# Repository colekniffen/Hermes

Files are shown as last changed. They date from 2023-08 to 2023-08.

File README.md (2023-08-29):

# Hermes
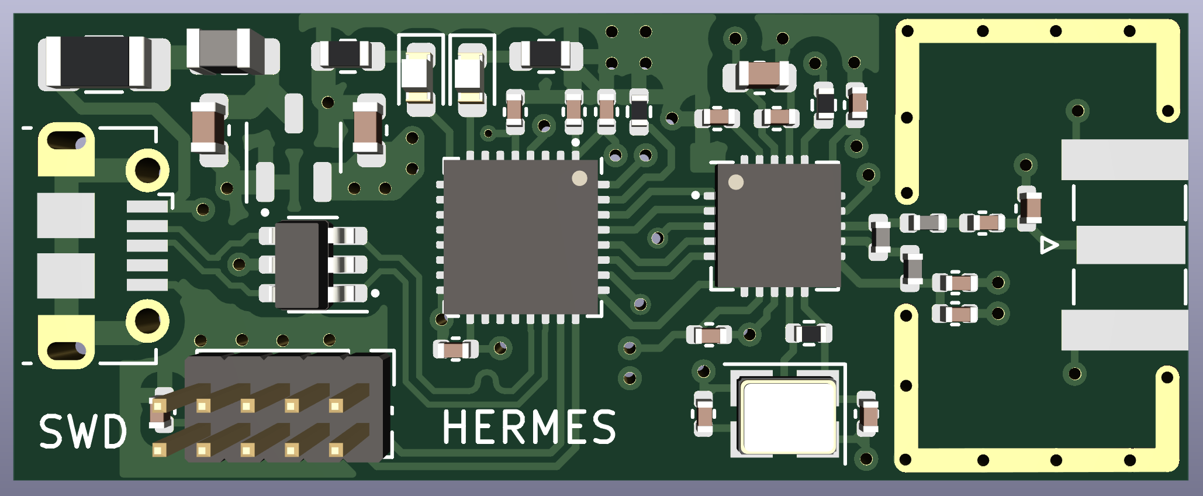
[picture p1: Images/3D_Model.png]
3D Model

A small form factor, low power, RF module with a programmable STM32.  The goal of this project was to make a small board to mess around with RF and some basic DSP.

## Stack-up
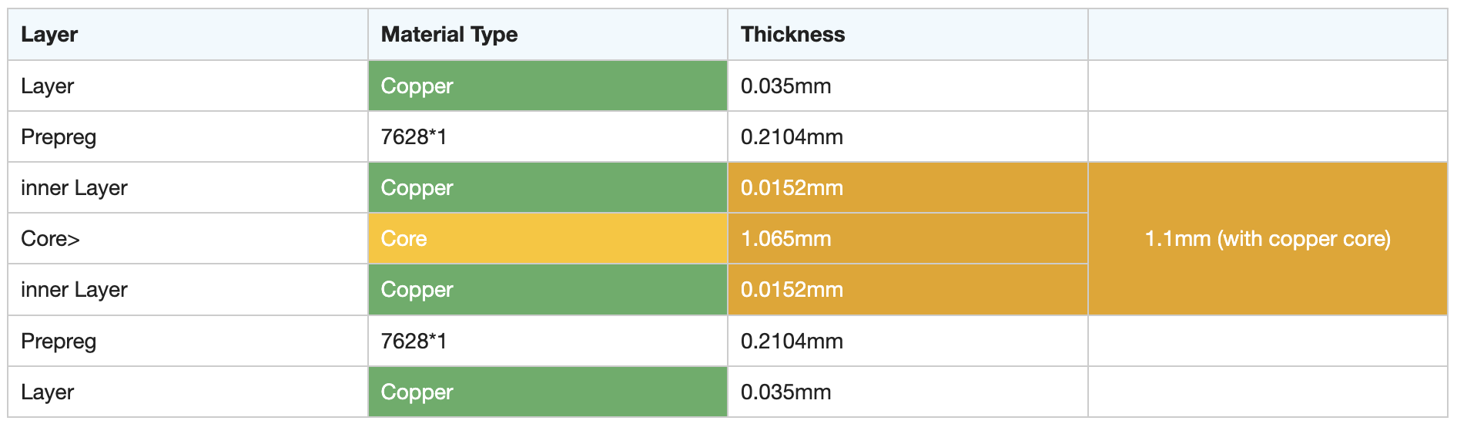
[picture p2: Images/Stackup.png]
PCB Stack-up

I planned to manufacture this board through JLC PCB.  The service allows for cost-effective manufacturing with reasonable accuracy and constraints.  I decided to use an impedance-controlled, 4-layer stack-up because of the RF section (JLC04161H-7628).  This board is 1.6 mm thick with an outer copper weight of 1oz and inner copper weight of 0.5oz.  The stack-up information is important in determining the USB differential and RF antenna trace widths and/or spacing. 

## Design Considerations
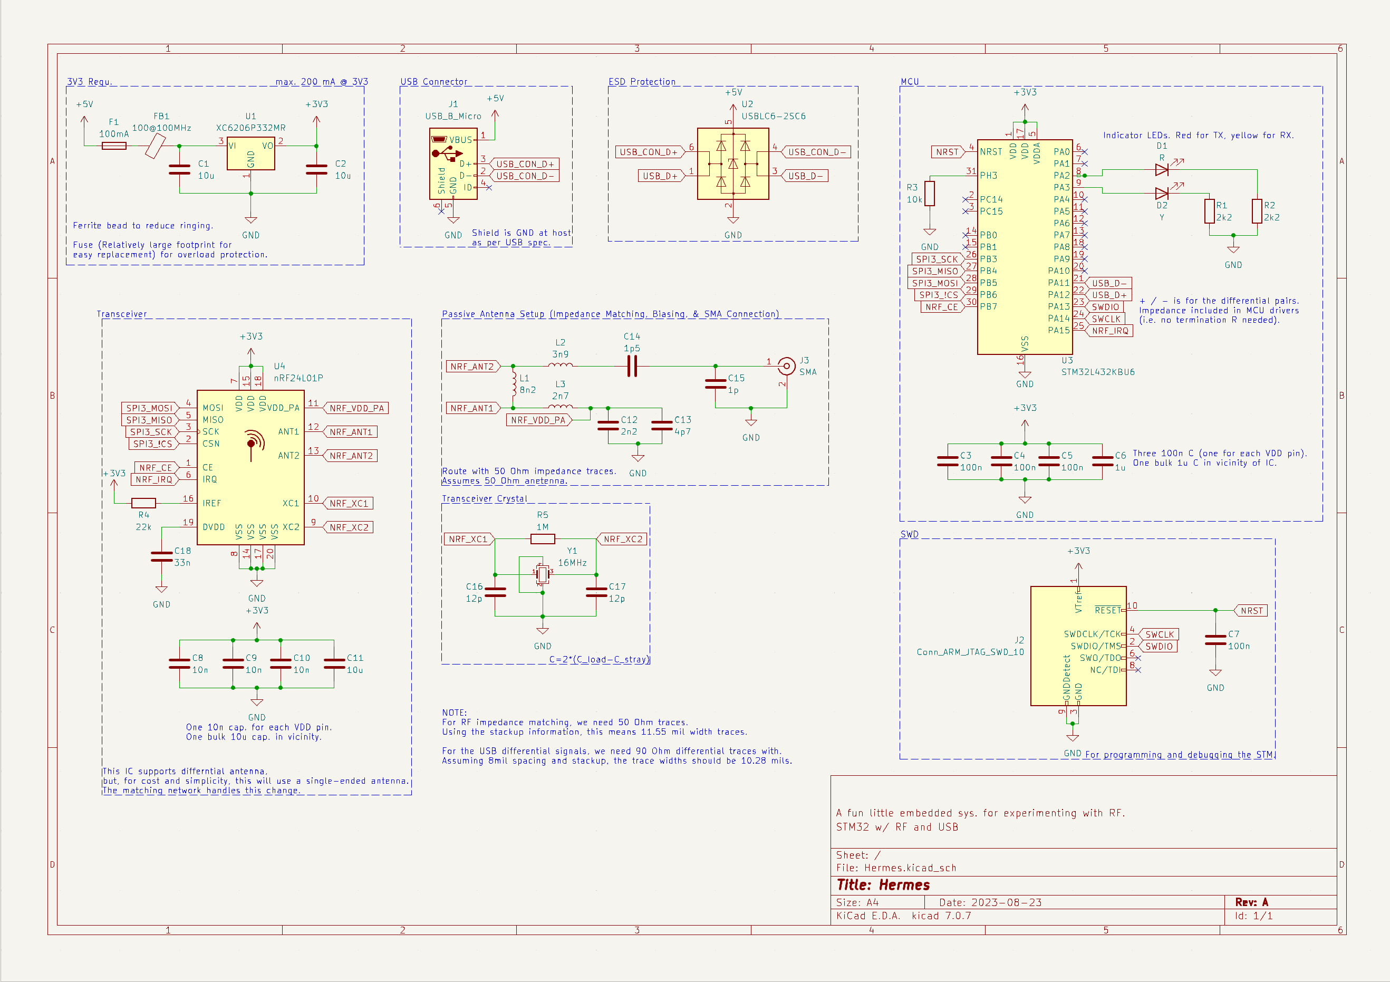
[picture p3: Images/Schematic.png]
Schematic
 
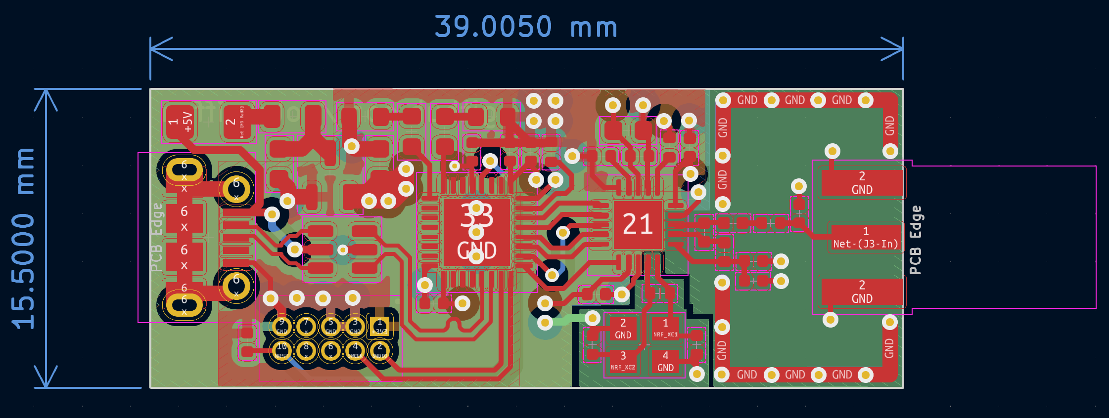
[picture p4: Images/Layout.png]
Layout


### USB Connection
I decided to use a micro-USB connection for this board.  I chose this connector mainly for its size.  I did consider using USB-C since it's becoming more prevalent in modern electronics and similar in size.  However, USB-C has many connections which would not be useful in this case.  I did not need anything incredibly high-speed or with high power demand.  If one wanted to use USB-C with this board, it's possible to basically just swap out the connector and terminate it as per the USB-C specifications for USB-C to micro-USB.  If this is done, it may be wise to add current protection.  I left current protection out mainly to reduce the number of components, and the likelihood of micro-USB (due to the shape) having reverse current is incredibly low.  I did still include ESD protection though.

USB uses differential signals.  The specification for the USB protocol is to have 90 Ohm impedance traces.  To do this, I assumed a trace spacing of 8 mils.  The spacing could be reduced, but I chose this for ease of manufacturing.  Using the stack-up information and the differential spacing, trace widths are calculated to be 10.28 mil.

### Power
The USB connection to a host device will provide the board with 5V.  Most of the components on the board are designed for 3V3, so a voltage regulator is needed.  I chose the XC6206P332MR.  This is an efficient, low cost, and low noise LDO regulator. 

### Microcontroller
I chose to use the STM32L432KBU6 for this board.  It's low power and has a built in USB module.  This MCU doesn't have a ton of memory, but it will be used mainly for passing the RX/TX signal along to the host and do basic processing.  So, it has more than enough memory for its intended use.  Additionally, the core speed is more than enough to handle the transceiver's data.  

Assuming a 1ns rise time, which is faster than expected for this setup, the critical length is around 41.1 mm.  This means as long as the traces are less than 41.1 mm, impedance effects can largely be ignored for the MCU's digital signals (the board isn't even that long!).  Furthermore, assuming worst-case propagation delay, based on the PCB materials, of 180 ps/in, the slight differences in trace length won't make a huge difference.  The SPI traces are short and the fastest setup/hold times are around 1.5 ns, so the slight difference in SPI trace lengths (the skew in delay for the SPI signals is approximately 37.4 ps) will have virtually no effect on performance.  If the MCU was operating at GHz frequencies, problems would likely arise, but this length difference is okay for the fastest signals supported by this system. 

### Transceiver
I chose the nRF24L01+ which is a 2.4GHz transceiver (using [GFSK](https://en.wikipedia.org/wiki/Frequency-shift_keying#Gaussian_frequency-shift_keying) modulation).  This transceiver contains basically everything needed to perform the functions of most consumer electronics, so it is more than enough for experimenting with.  It has good documentation, a decent amount of customizability, and doesn't use a ton of power.  Additionally, The IC supports a variety of different antenna configurations, but I planned to connect a 2.4GHz passive, single-ended antenna.  Thus, I included the necessary matching and bias networks (assuming a 50 Ohm antenna) to meet the specifications as described by the data sheet.

To meet the impedance matching requirements, the antenna traces are to be 50 Ohms.  Using the stack-up information, the calculated trace width is 11.55mil.

## Datasheets
- [STM Datasheet](https://www.st.com/content/ccc/resource/technical/document/datasheet/24/01/9f/59/f0/83/47/fc/DM00257205.pdf/files/DM00257205.pdf/jcr:content/translations/en.DM002572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)
- [Transceiver Datasheet](https://www.sparkfun.com/datasheets/Components/SMD/nRF24L01Pluss_Preliminary_Product_Specification_v1_0.pdf)
- [ Linear and low-dropout regulator](https://www.mouser.com/datasheet/2/760/TOSL_S_A0007229533_1-2575067.pdf)

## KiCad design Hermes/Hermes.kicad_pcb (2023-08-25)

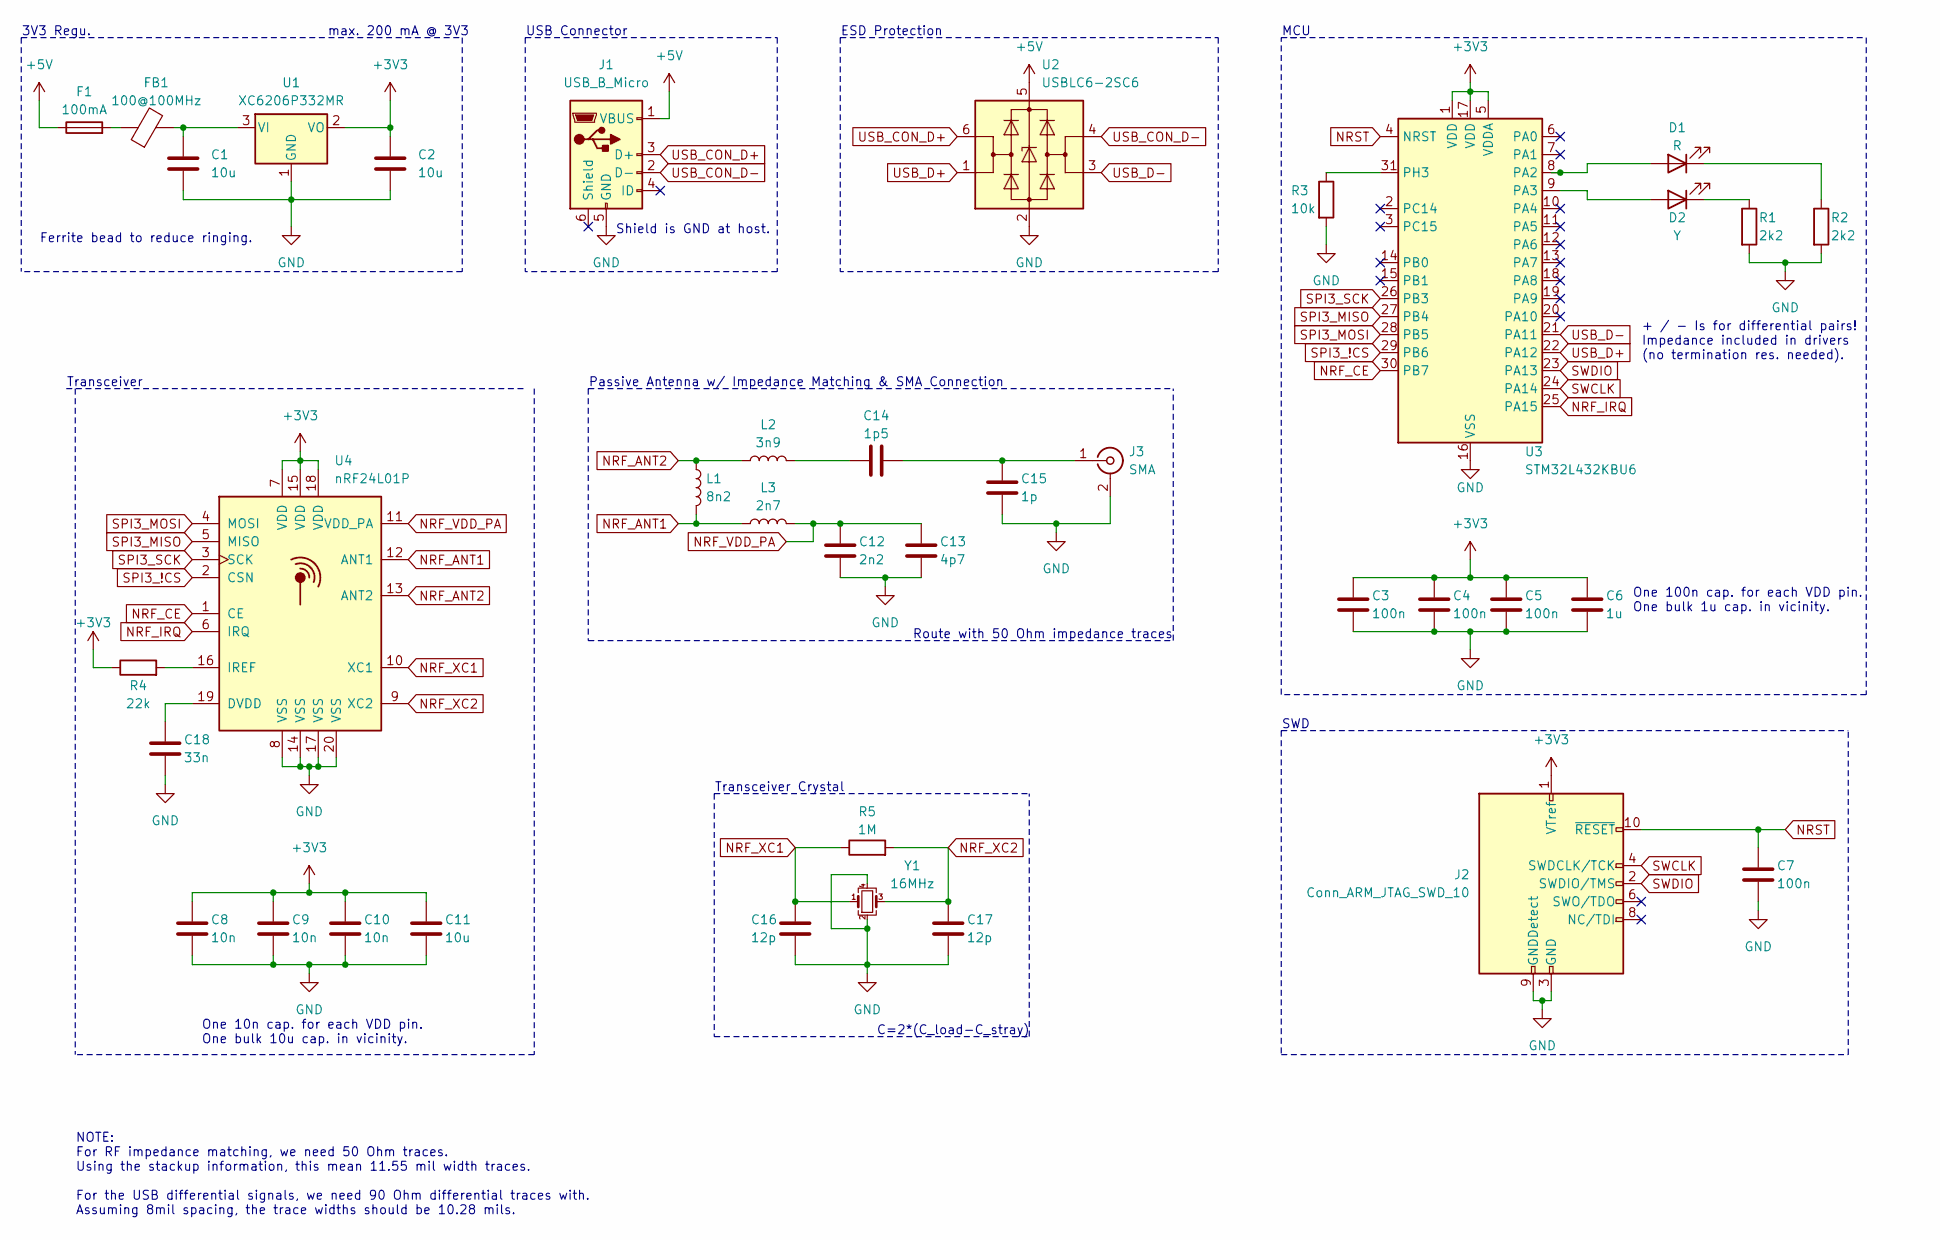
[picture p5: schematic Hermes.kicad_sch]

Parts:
C1, C2, C11: 10u; C_0603_1608Metric
C3, C4, C5, C7: 100n; C_0402_1005Metric
C6: 1u; C_0402_1005Metric
C8, C9, C10: 10n; C_0402_1005Metric
C12: 2n2; C_0402_1005Metric
C13: 4p7; C_0402_1005Metric
C14: 1p5; C_0402_1005Metric
C15: 1p; C_0402_1005Metric
C16, C17: 12p; C_0402_1005Metric
C18: 33n; C_0402_1005Metric
D1: R; LED_0603_1608Metric
D2: Y; LED_0603_1608Metric
F1: 100mA; Fuse_1206_3216Metric_Pad1.42x1.75mm_HandSolder
FB1: 100@100MHz; L_0805_2012Metric
J1: USB_B_Micro; USB_Micro-B_Molex-105017-0001
J2: Conn_ARM_JTAG_SWD_10; PinHeader_2x05_P1.27mm_Vertical
J3: SMA; SMA_Samtec_SMA-J-P-X-ST-EM1_EdgeMount
L1: 8n2; L_0402_1005Metric
L2: 3n9; L_0402_1005Metric
L3: 2n7; L_0402_1005Metric
R1, R2: 2k2; R_0603_1608Metric
R3: 10k; R_0402_1005Metric
R4: 22k; R_0402_1005Metric
R5: 1M; R_0402_1005Metric
U1: XC6206P332MR; SOT-23-3
U2: USBLC6-2SC6; SOT-23-6
U3: STM32L432KBU6; QFN-32-1EP_5x5mm_P0.5mm_EP3.45x3.45mm
U4: nRF24L01P; QFN-20-1EP_4x4mm_P0.5mm_EP2.5x2.5mm
Y1: 16MHz; Crystal_SMD_3225-4Pin_3.2x2.5mm

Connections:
+3V3: C2.1, C3.1, C4.1, C5.1, C6.1, C8.1, C9.1, C10.1, C11.1, J2.1 (VTref), R4.1, U1.2 (VO), U3.1 (VDD), U3.5 (VDDA), U3.17 (VDD), U4.7 (VDD), U4.15 (VDD), U4.18 (VDD)
+5V: F1.1, J1.1 (VBUS), U2.5 (VBUS)
GND: C1.2, C2.2, C3.2, C4.2, C5.2, C6.2, C7.2, C8.2, C9.2, C10.2, C11.2, C12.2, C13.2, C15.1, C16.2, C17.2, C18.2, J1.5 (GND), J2.3 (GND), J2.5 (GND), J2.9 (GNDDetect), J3.2 (Ext), R1.2, R2.2, R3.2, U1.1 (GND), U2.2 (GND), U3.16 (VSS), U3.32 (VSS), U3.33 (VSS), U4.8 (VSS), U4.14 (VSS), U4.17 (VSS), U4.20 (VSS), Y1.2, Y1.4
NRF_ANT1: L1.2, L3.1, U4.12 (ANT1)
NRF_ANT2: L1.1, L2.1, U4.13 (ANT2)
NRF_CE: U3.30 (PB7), U4.1 (CE)
NRF_IRQ: U3.25 (PA15), U4.6 (IRQ)
NRF_VDD_PA: C12.1, C13.1, L3.2, U4.11 (VDD_PA)
NRF_XC1: C16.1, R5.1, U4.10 (XC1), Y1.1
NRF_XC2: C17.1, R5.2, U4.9 (XC2), Y1.3
NRST: C7.1, J2.10 (~RESET), U3.4 (NRST)
unnamed: C14.1, L2.2
unnamed: D1.2 (A), U3.8 (PA2)
unnamed: D1.1 (K), R2.1
unnamed: D2.2 (A), U3.9 (PA3)
unnamed: D2.1 (K), R1.1
unnamed: F1.2, FB1.1
unnamed: C14.2, C15.2, J3.1 (In)
unnamed: C1.1, FB1.2, U1.3 (VI)
unnamed: R3.1, U3.31 (PH3)
unnamed: C18.1, U4.19 (DVDD)
unnamed: R4.2, U4.16 (IREF)
SPI3_!CS: U3.29 (PB6), U4.2 (CSN)
SPI3_MISO: U3.27 (PB4), U4.5 (MISO)
SPI3_MOSI: U3.28 (PB5), U4.4 (MOSI)
SPI3_SCK: U3.26 (PB3), U4.3 (SCK)
SWCLK: J2.4 (SWDCLK/TCK), U3.24 (PA14)
SWDIO: J2.2 (SWDIO/TMS), U3.23 (PA13)
USB_CON_D+: J1.3 (D+), U2.6 (I/O1)
USB_CON_D-: J1.2 (D-), U2.4 (I/O2)
USB_D+: U2.1 (I/O1), U3.22 (PA12)
USB_D-: U2.3 (I/O2), U3.21 (PA11)

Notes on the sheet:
Transceiver Crystal
NOTE: For RF impedance matching, we need 50 Ohm traces. Using the stackup information, this mean 11.55 mil width traces. For the USB differential signals, we need 90 Ohm differential traces with. Assuming 8mil spacing, the trace widths should be 10.28 mils.
C=2*(C_load-C_stray)
One 100n cap. for each VDD pin. One bulk 1u cap. in vicinity.
USB Connector
Shield is GND at host.
max. 200 mA @ 3V3
Passive Antenna w/ Impedance Matching & SMA Connection
Route with 50 Ohm impedance traces
Ferrite bead to reduce ringing.
Transceiver
SWD
One 10n cap. for each VDD pin. One bulk 10u cap. in vicinity.
MCU
+ / - Is for differential pairs! Impedance included in drivers (no termination res. needed).
ESD Protection
3V3 Regu.

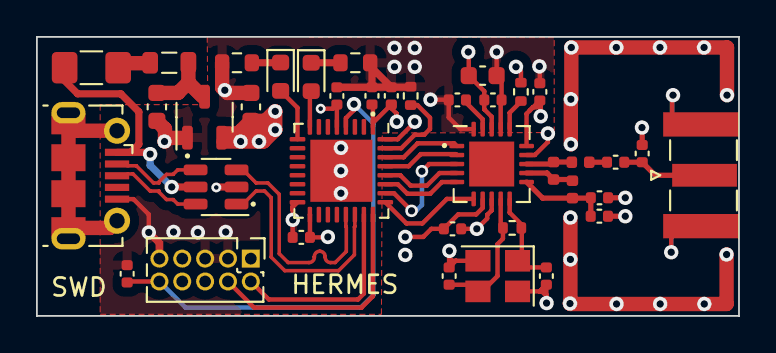
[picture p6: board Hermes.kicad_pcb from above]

Board: 4 copper layers, 39.0 x 15.5 mm, 38 parts (0 on the bottom side), 32 nets.

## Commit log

2023-08-25 Board and schematic
    [Hermes.kicad_pcb, Hermes.kicad_sch]
2023-08-25 Cleanup files and comments
    [Hermes.kicad_pcb]
2023-08-25 Updating schematic comments
    [Hermes.kicad_sch]
2023-08-26 Update schematic image in readme
